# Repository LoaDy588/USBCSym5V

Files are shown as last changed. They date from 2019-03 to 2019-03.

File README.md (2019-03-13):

# USBC Symetric 5V Power module

Continued from https://github.com/JarekParal/USBCPowerModule.

## Device
### TPS65131
Split-Rail Converter with Dual, Positive and Negative Outputs (750mA typ)    	
http://www.ti.com/product/tps65131   
http://www.ti.com/lit/gpn/tps65131   

### LM2990
1-A, Negative Low Dropout Regulator  
http://www.ti.com/product/lm2990    
http://www.ti.com/lit/gpn/lm2990   

### LM2940C
1A Low Dropout Regulator   
http://www.ti.com/product/lm2940c   
http://www.ti.com/lit/ds/symlink/lm2940c.pdf    

## Problems
 * Still not tested at full power capability, according to datasheet calculations it is overloaded by factor of 2 at full 1A output

 * TPS65131 is seemingly the most powerful split rail converter, higher currents would require separate boost and inverting converters.

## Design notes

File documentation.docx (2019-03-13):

# USB-C +5/-5v pOWER MODULE

O. Pecák, FI MUNI

# Zadání

Symetrický +5/-5V napájecí modul, napájený přes USB Type-C konektor. 1,5+ ampér na pozitivní větvi, 1+ ampér na negativní větvi.

# revize + aktuální problémy

### 13.3.2018 – Rev. 2

- Opraven/přidán filtr na negativní feedback pro stabilizaci
- Změna elektrolitických kondenzátorů na tantalové
- Lehké úpravy layoutu

### 26.8.2018 – Rev. 1

- První návrh
- Negativní větev nereguluje správně – osciluje feedback – fix (přidat 100k odpor do série na negativní feedback)
- Netestováno na full load

# BOM(Rev.2)

Reference | Qty | Part | Link
U1 | 1 | TI TPS65131 | Farnell (https://cz.farnell.com/texas-instruments/tps65131rget/ic-conv-dc-dc-pos-neg-24-qfn/dp/1755480)
U2 | 1 | TI LM2940CSX-5.0/NOPB | Farnell (https://cz.farnell.com/texas-instruments/lm2940csx-5-0-nopb/ldo-volt-reg-1a-5v-to-263-3/dp/2783569)
U3 | 1 | LM2990S-5.0 | Farnell (https://cz.farnell.com/texas-instruments/lm2990s-5-0-nopb/ic-v-reg-linear-5v/dp/1469082)
D1, D2 | 2 | VISHAY B340A-E3/61T – 3A, Schottky | Farnell (https://cz.farnell.com/vishay/b340a-e3-61t/rectifier-standard-3a-40v-do-214ac/dp/2335183)
C1, C3, C10, C12-C18 | 11 | 4.7uF, 25V, X7R, Ceramic, 1210 SMD | Farnell (https://cz.farnell.com/kemet/c1210x475k3ractu/cap-mlcc-4-7uf-25v-1210/dp/2906192)
C2 | 1 | 100nF, 50V, X7R, Ceramic, 0603 SMD | Farnell (https://cz.farnell.com/vishay/ga0603y104kbaat31g/cap-mlcc-aec-q200-x7r-0-1uf-0603/dp/2896285)
C7, C9 | 2 | 12pF, 50V, X7R, Ceramic, 0603 SMD | Farnell (https://cz.farnell.com/kemet/c0603c120k5ractu/cap-mlcc-x7r-12pf-50v-0603/dp/2821150)
C6 | 1 | 220nF, 16V, X5R, Ceramic, 0603 SMD | Farnell (https://cz.farnell.com/wurth-elektronik/885012106013/cap-mlcc-x5r-0-22uf-16v-0603/dp/2812268)
C5 | 1 | 10nF, 25V, X7R, Ceramic, 0603 SMD | Farnell (https://cz.farnell.com/yageo/cc0603krx7r8bb103/cap-mlcc-x7r-10nf-25v-0603/dp/3019561)
C8 | 1 | 4.7nF, 50V, X7R, Ceramic, 0603 SMD | Farnell (https://cz.farnell.com/kemet/c0603c472j5ractu/cap-mlcc-x7r-4700pf-50v-0603/dp/2409042)
C4, C11 | 2 | 47uF Tantal, 25V, Kemmet-D (2917) SMD | Farnell (https://cz.farnell.com/kemet/t491x476k025at/cap-47-f-25v-10-2917-smd/dp/1457545)
L1 | 1 | KEMET MPLC0730L2R2 | Farnell (https://cz.farnell.com/kemet/mplc0730l2r2/inductor-power-2-2uh-20-smd/dp/2364586)
L2 | 1 | KEMET MPLC0730L3R3 | Farnell (https://cz.farnell.com/kemet/mplc0730l3r3/inductor-power-3-3uh-20-smd/dp/2364592)
R1 | 1 | 100R resistor, 0603 SMD | Farnell (https://cz.farnell.com/yageo/rc0603fr-07100rl/res-100r-0-01-0-1w-0603-thick/dp/9238360)
R2, R5 | 2 | 130K resistor, 0603 SMD | Farnell (https://cz.farnell.com/panasonic-electronic-components/erj3geyj134v/res-130k-0-05-0-1w-0603-thick/dp/2059658)
R4 | 1 | 536K resistor, 0603 SMD | Farnell (https://cz.farnell.com/multicomp/mcwr06x5363ftl/res-536k-0-01-0-1w-0603-thick/dp/2694894)
R3 | 1 | 665K resistor, 0603 SMD | Farnell (https://cz.farnell.com/panasonic-electronic-components/erj3ekf6653v/res-665k-1-100mw-0603-thick-film/dp/2303304)
R6 | 1 | 100K resistor, 0603 SMD | Farnell (https://cz.farnell.com/multicomp/mcwr06x1003ftl/res-100k-1-0-1w-0603-thick-film/dp/2447226)
J1 | 1 | AMPHENOL 12401548E4-2A | Farnell (https://cz.farnell.com/amphenol-icc-commercial-products/12401548e4-2a-500/usb-connector-3-1-type-c-rcpt/dp/2564554)

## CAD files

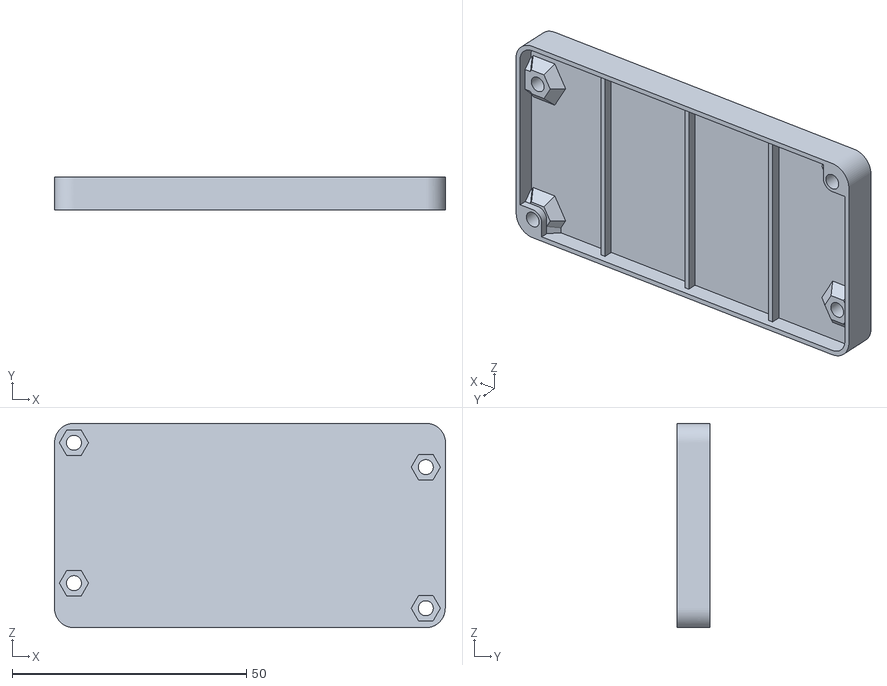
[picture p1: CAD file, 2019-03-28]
case/Bottom Part.stl
83.4 x 7.10 x 43.6

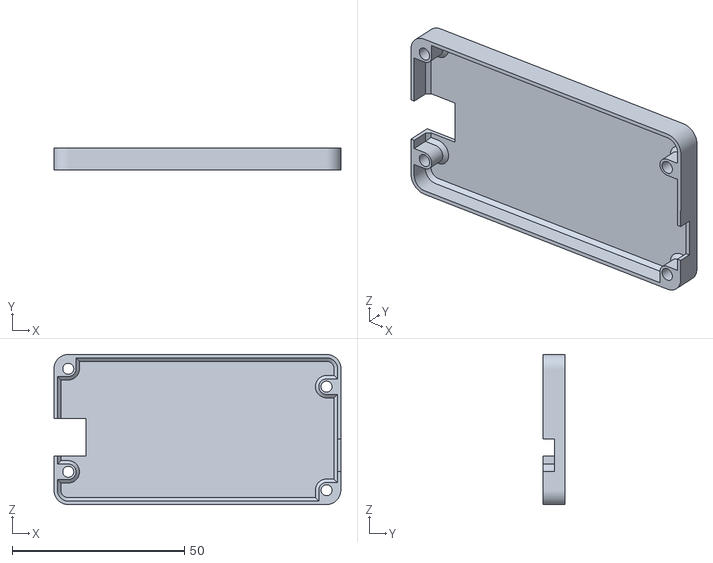
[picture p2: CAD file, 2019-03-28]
case/Top Part.stl
83.4 x 6.40 x 43.6

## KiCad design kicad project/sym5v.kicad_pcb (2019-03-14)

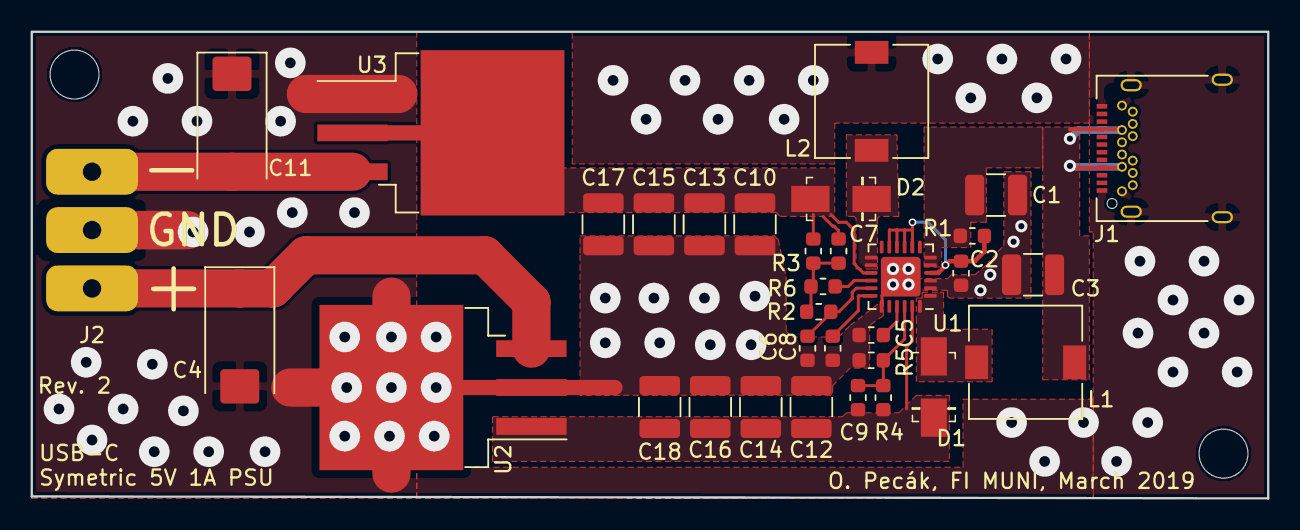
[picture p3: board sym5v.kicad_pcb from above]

Board: 2 copper layers, 80.8 x 30.5 mm, 33 parts (0 on the bottom side), 15 nets.

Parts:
C1, C3, C10, C12, C13, C14, C15, C16, C17, C18: 4.7uF; C_1210_3225Metric
C2: 100nF; C_0603_1608Metric
C4, C11: 47uF; CP_EIA-7343-31_Kemet-D_Pad2.25x2.55mm_HandSolder
C5: 10nF; C_0603_1608Metric
C6: 220nF; C_0603_1608Metric
C7: 10pF or 12pF; C_0603_1608Metric
C8: 4.7nF; C_0603_1608Metric
C9: 12pF; C_0603_1608Metric
D1, D2: D_Schottky; DO-214AC
J1: USB_C_Receptacle; USB_C_Receptacle_Amphenol_12401548E4-2A
J2: Conn_01x03; SolderWirePad_1x03_P3.81mm_Drill1.2mm
L1: 2.2uH; L_7.3x7.3_H3.5
L2: 3.3uH; L_7.3x7.3_H3.5
R1: 100R; R_0603_1608Metric
R2, R5: 130K; R_0603_1608Metric
R3: 665K; R_0603_1608Metric
R4: 536K; R_0603_1608Metric
R6: 100K; R_0603_1608Metric
U1: TPS6513x; QFN-24-1EP_4x4mm_P0.5mm_EP2.6x2.6mm
U2: LM2940; TO-263-3_TabPin4
U3: LM2990SX-5.0; TO-263-3_TabPin2

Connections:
+5V: C4.1, J2.1, U2.3
-5V: C11.2, J2.3, U3.3
GND: C1.2, C2.2, C3.2, C4.2, C5.2, C6.2, C8.2, C10.2, C11.1, C12.2, C13.2, C14.2, C15.2, C16.2, C17.2, C18.2, J1.A1, J1.A12, J1.B1, J1.B12, J1.S1, J2.2, L2.2, R5.2, U1.2, U1.3, U1.19, U2.2, U2.4, U3.1
unnamed: C2.1, R1.1, U1.4, U1.8, U1.9, U1.10, U1.11
unnamed: C5.1, U1.21
unnamed: C6.1, R2.1, U1.17
unnamed: C7.1, R2.2, R3.1, R6.1
unnamed: C8.1, U1.18
unnamed: C9.2, R4.2, R5.1, U1.22
unnamed: D1.2, L1.2, U1.1, U1.24
unnamed: D2.1, L2.1, U1.13, U1.14
unnamed: R6.2, U1.16
VIN: C1.1, C3.1, J1.A4, J1.A9, J1.B4, J1.B9, L1.1, R1.2, U1.5, U1.6
VNEG: C7.2, C10.1, C13.1, C15.1, C17.1, D2.2, R3.2, U1.15, U3.2
VPOS: C9.1, C12.1, C14.1, C16.1, C18.1, D1.1, R4.1, U1.23, U2.1

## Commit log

2019-03-13 Rev 2 schematic - broken symbols!
    [sym5v.sch]
2019-03-13 rev2 final
    [sym5v.kicad_pcb, sym5v.sch]
2019-03-14 add mounting holes
    [sym5v.kicad_pcb]
2019-03-28 Add case
    [Bottom Part.stl, Top Part.stl]
